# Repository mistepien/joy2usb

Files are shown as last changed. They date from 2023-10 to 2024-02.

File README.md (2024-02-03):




# joy2usb
Atari-like joystick adapter to USB.

<a href="https://github.com/mistepien/joy2usb/blob/main/joy2usb.pdf">Adapter</a> is actually a shield for 
<a href="https://learn.sparkfun.com/tutorials/pro-micro--fio-v3-hookup-guide/hardware-overview-pro-micro">Arduino Pro Micro based on ATmega 32U4</a>.

ATmega 32U4 has a hardware support for fullspeed USB, thus <a href="https://wiki.archlinux.org/title/mouse_polling_rate">polling rate 1000Hz</a> is not an issue for that chip.

You can use the <a href="https://github.com/mistepien/joy2usb/blob/main/production/joy2usb_6.2_2023-10-14_00-56-38/joy2usb_6.2.zip">gerber file<a> to order the PCB.

Attached   <a href="https://github.com/mistepien/joy2usb/blob/main/joy2usb.ino">code</a> uses port registers so that is quite efficient, debouncing is done without delay() function.

The adapter has a toggle C64/Amiga for choosing C64 or Amiga approach for FIRE2/FIRE3. According to <a href="http://wiki.icomp.de/wiki/DE-9_Joystick"> wiki.icomp.de website about DE-9 joystick</a>, FIRE2/FIRE3 are pulled to VCC in case of C64 and to GND in case of Amiga. That is not an issue for joy2usb due to XOR magic.

Two footprints are not trivial: DB9 male socket (<b>J1</b>) and SPDT switch (<b>SW2</b>).

Officialy the <b>J1</b> footprint (joy2usb has been designed in <a href="https://www.kicad.org/">KiCad</a>) is "DSUB-9_Male_Horizontal_P2.77x2.84mm_EdgePinOffset9.90mm_Housed_MountingHolesOffset11.32mm"
however it was chosen to fit <a href="https://www.tme.eu/pl/en/details/ld09p13a4gx00lf/d-sub-plugs-and-sockets/amphenol-communications-solutions/">   LD09P13A4GX00LF Amphenol</a>.

<b>SW2</b> supposed to be <a href="https://www.tme.eu/pl/en/details/mfp1220/slide-switches/knitter-switch/mfp-1220">Switch SPDT MFP 1220 KNITTER-SWITCH</a>, but it can be replaced with Pinheader 1x3/1x2 (pitch terminal 2.54mm) + jumper or any other SPDT switch with 3 pins and pitch terminal 2.54mm (e.g. <a href="https://www.tme.eu/pl/details/eg1218/przelaczniki-suwakowe/e-switch/">EG1218 E-SWITCH</a>).

<b>J2</b> is redundant -- you can use it to add some new features like autofire switch or sth. In attached firmware connecting PF4 to GND disables debouncing procedure. <b>If you connect PF5 to GND you can read FIRE1 CPS ("$cat /dev/ttyACM0" in Linux).</b>

Sometimes during uploading code to Arduino board you may face some issues -- then you will need to use RESET -- so <b>SW1</b> can be useful if you like to develope your own code.

BOM:
| Qty	| Reference(s) | Description |
|-----|---|---|
|3 | D1, D2, D3 | LEDs 3mm |  
|1 |	J1|	DB9 Male Connector <a href="https://www.tme.eu/pl/en/details/ld09p13a4gx00lf/d-sub-plugs-and-sockets/amphenol-communications-solutions/"> LD09P13A4GX00LF Amphenol</a> |
|1 |	J2|	2x4 Pinheader. pitch terminal: 2.54mm |
|3 | R1, R2, R3 | resistors for D1, D2 and D3 |
|2 | R4, R5	| resistors 10KΩ |
|1 | SW1 | Tact switch from Arduino breadboard projects |
|1 | SW2 | <a href="https://www.tme.eu/pl/en/details/mfp1220/slide-switches/knitter-switch/mfp-1220">Switch SPDT MFP 1220 KNITTER-SWITCH</a> |
|1 | U1 |	DIP20 socket (width 15.24mm) + <a href="https://learn.sparkfun.com/tutorials/pro-micro--fio-v3-hookup-guide/hardware-overview-pro-micro">Arduino Pro Micro</a> |

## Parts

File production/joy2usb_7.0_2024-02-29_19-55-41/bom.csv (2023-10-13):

Designator | Footprint | Quantity | Value | LCSC Part #
D1 | LED_D3.0mm_Oval | 1 | AMIGA
D2 | LED_D3.0mm_Oval | 1 | C64
D3 | LED_D3.0mm_Oval | 1 | STATUS
J1 | DSUB-9_Male_Horizontal_P2.77x2.84mm_EdgePinOffset9.90mm_Housed_OVAL_MountingHolesOffset11.32mm | 1 | DB9_Male
J2 | PinHeader_2x04_P2.54mm_Vertical | 1 | Conn_02x04_Odd_Even
R1, R2, R5 | R_Axial_DIN0207_L6.3mm_D2.5mm_P10.16mm_Horizontal_Oval | 3 | RxΩ
R3, R4 | R_Axial_DIN0207_L6.3mm_D2.5mm_P10.16mm_Horizontal_Oval | 2 | R10KΩ
SW1 | SW_PUSH_6mm_H4.3mm | 1 | RST
SW2 | E-Switch-EG1218-Manufacturer_Recommended_Oval | 1 | C64MODESW
U1 | DIP-24_W15.24mm_Socket_LongPads | 1 | Arduino_Pro_Micro

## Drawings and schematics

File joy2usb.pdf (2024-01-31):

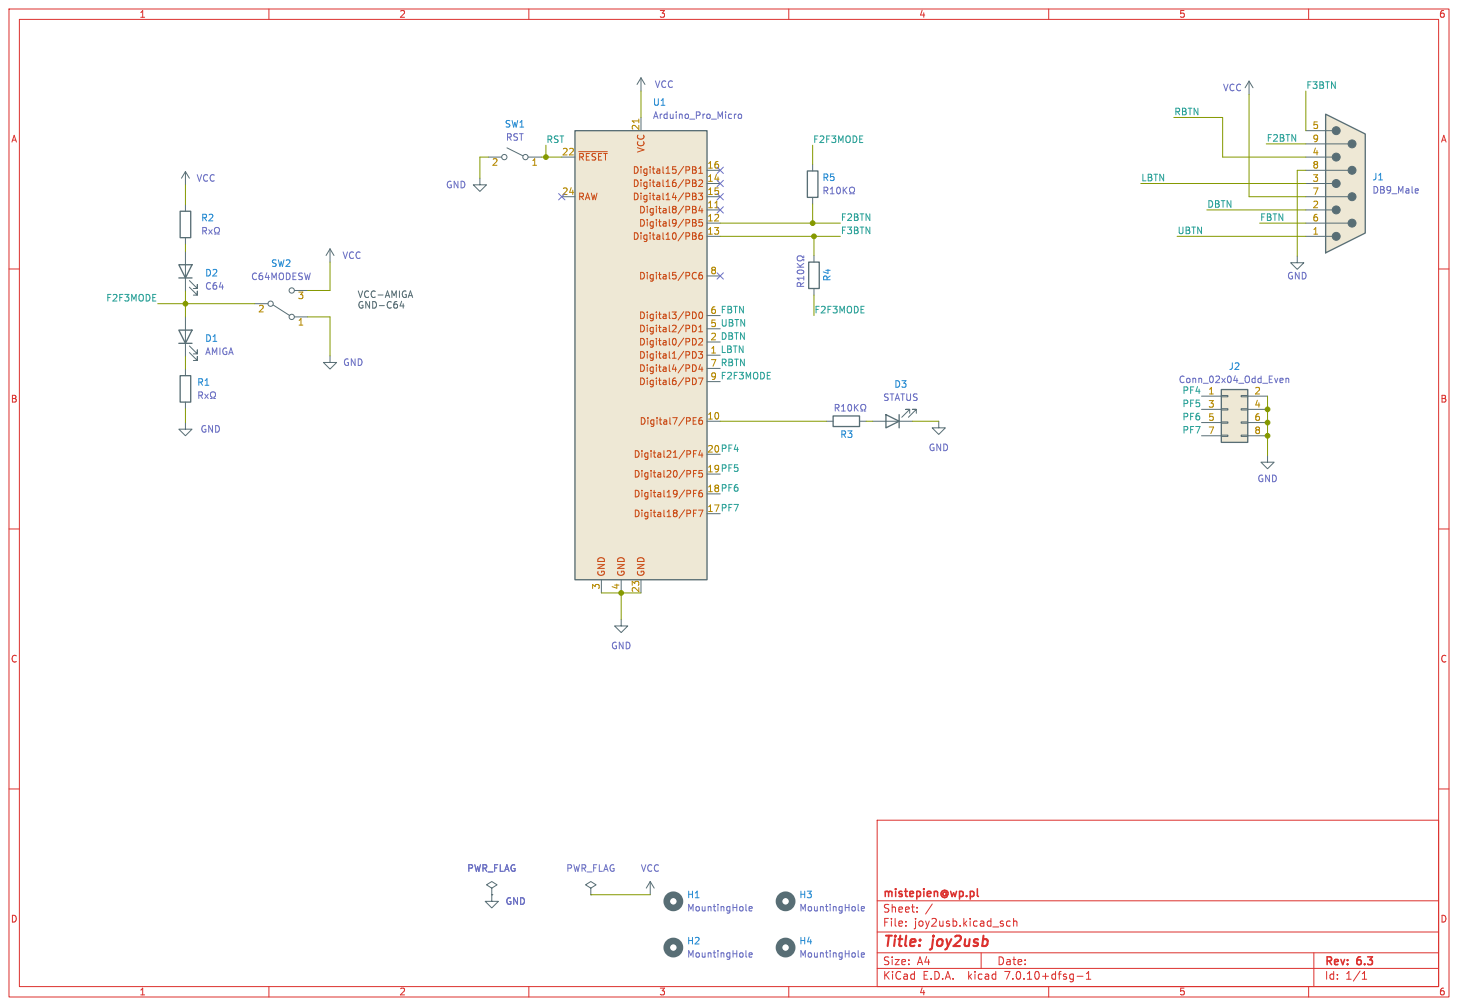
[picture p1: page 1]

File: joy2usb.kicad_sch Sheet: / mistepien@wp.pl R4 þÿR10K© D2 C64 R2

H4 MountingHole H3 MountingHole H1 MountingHole H2 MountingHole

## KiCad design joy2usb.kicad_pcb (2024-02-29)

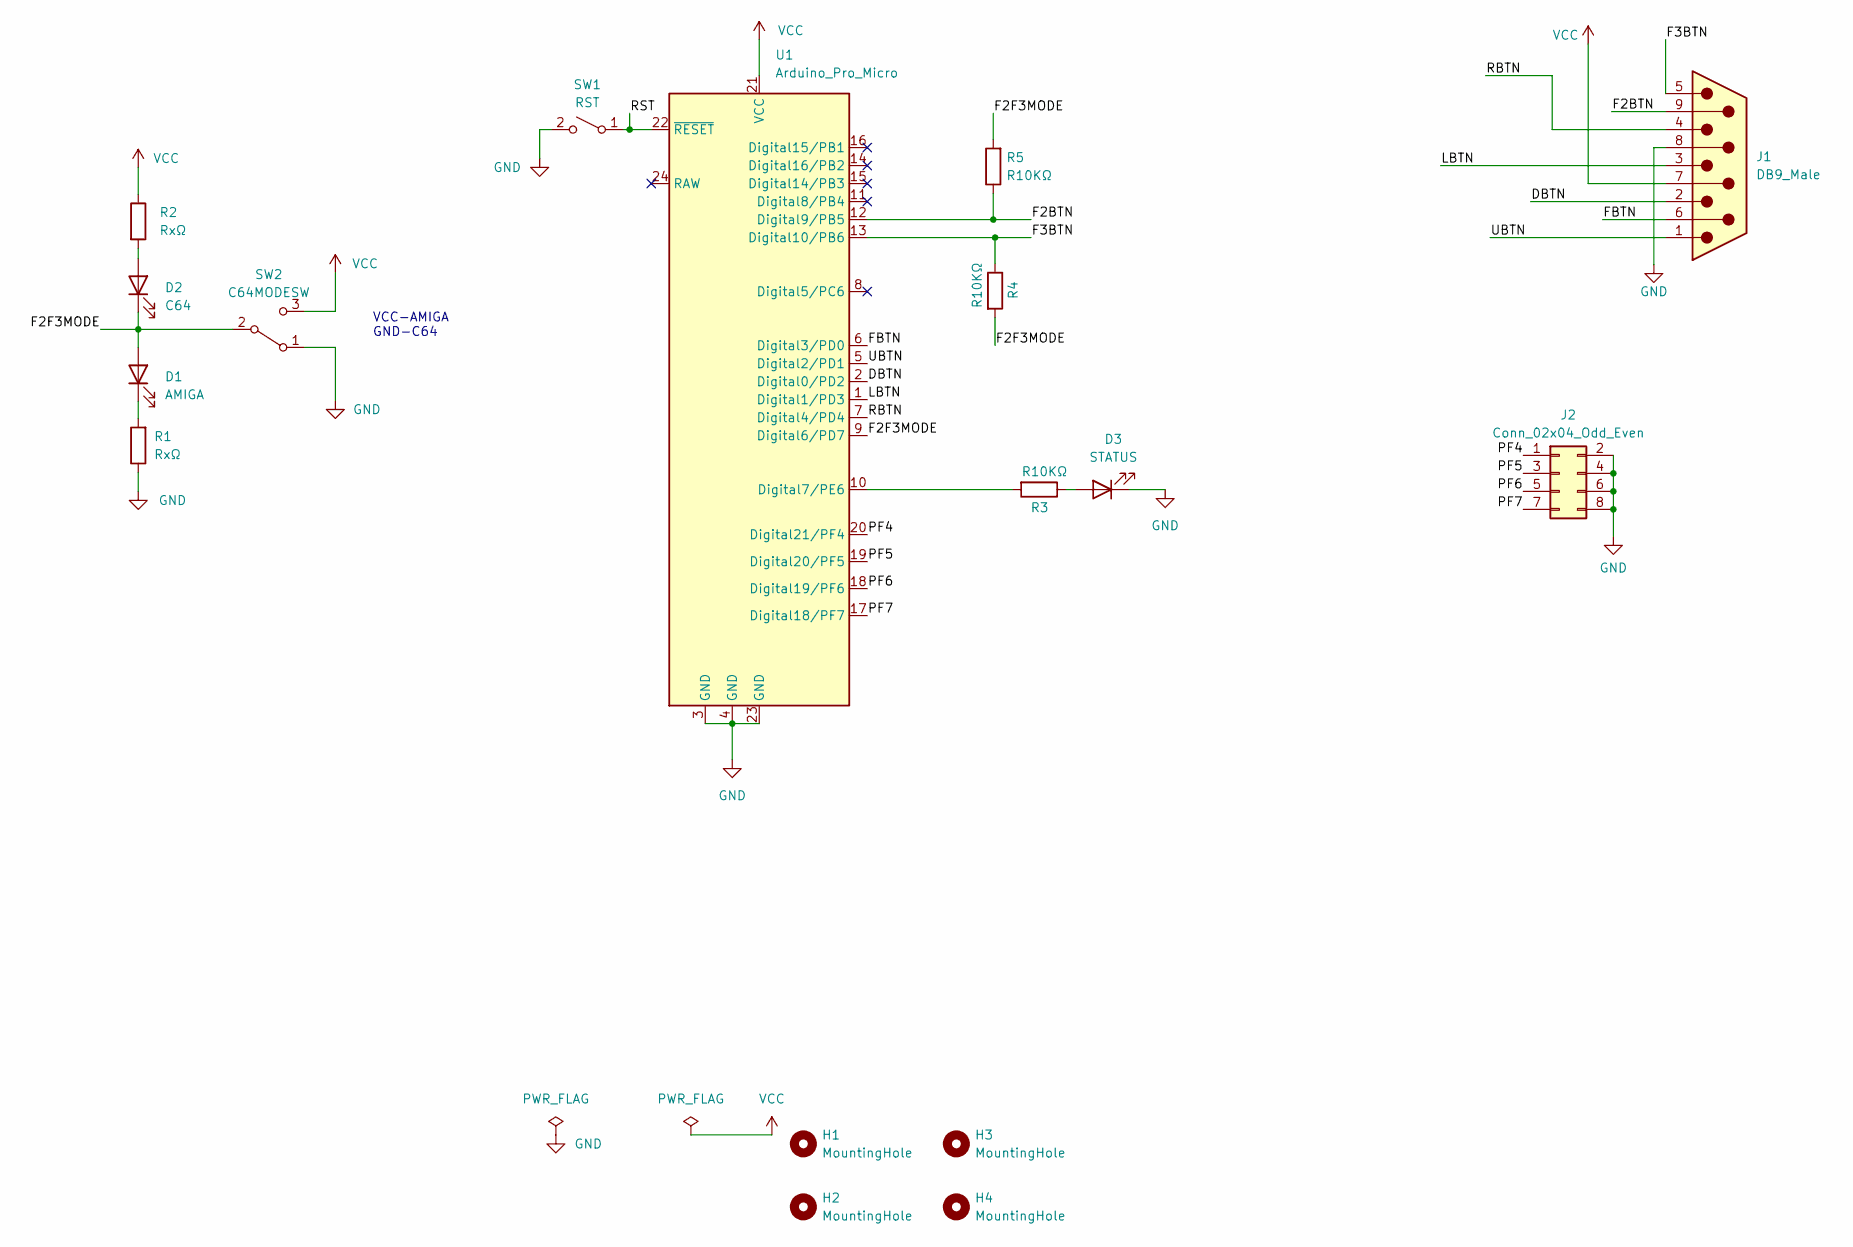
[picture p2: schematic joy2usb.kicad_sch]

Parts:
D1: AMIGA; LED_D3.0mm_Oval
D2: C64; LED_D3.0mm_Oval
D3: STATUS; LED_D3.0mm_Oval
H1, H2, H3, H4: MountingHole; MountingHole_3.5mm
J1: DB9_Male; DSUB-9_Male_Horizontal_P2.77x2.84mm_EdgePinOffset9.90mm_Hou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
J2: Conn_02x04_Odd_Even; PinHeader_2x04_P2.54mm_Vertical
R1, R2: RxΩ; R_Axial_DIN0207_L6.3mm_D2.5mm_P10.16mm_Horizontal_Oval
R3, R4, R5: R10KΩ; R_Axial_DIN0207_L6.3mm_D2.5mm_P10.16mm_Horizontal_Oval
SW1: RST; SW_PUSH_6mm_H4.3mm
SW2: C64MODESW; E-Switch-EG1218-Manufacturer_Recommended_Oval
U1: Arduino_Pro_Micro; DIP-24_W15.24mm_Socket_LongPads

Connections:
/DBTN: J1.2, U1.2 (Digital0/PD2)
/F2BTN: J1.9, R5.1, U1.12 (Digital9/PB5)
/F2F3MODE: D1.2 (A), D2.1 (K), R4.2, R5.2, SW2.2 (B), U1.9 (Digital6/PD7)
/F3BTN: J1.5, R4.1, U1.13 (Digital10/PB6)
/FBTN: J1.6, U1.6 (Digital3/PD0)
/LBTN: J1.3, U1.1 (Digital1/PD3)
/PF4: J2.1, U1.20 (Digital21/PF4)
/PF5: J2.3, U1.19 (Digital20/PF5)
/PF6: J2.5, U1.18 (Digital19/PF6)
/PF7: J2.7, U1.17 (Digital18/PF7)
/RBTN: J1.4, U1.7 (Digital4/PD4)
/RST: SW1.1 (A), U1.22 (~RESET)
/UBTN: J1.1, U1.5 (Digital2/PD1)
GND: D3.1 (K), J1.8, J2.2, J2.4, J2.6, J2.8, R1.1, SW1.2 (B), SW2.1 (A), U1.3 (GND), U1.4 (GND), U1.23 (GND)
unnamed: D1.1 (K), R1.2
unnamed: D2.2 (A), R2.2
unnamed: D3.2 (A), R3.1
unnamed: R3.2, U1.10 (Digital7/PE6)
VCC: J1.7, R2.1, SW2.3 (C), U1.21 (VCC)

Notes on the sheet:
VCC-AMIGA GND-C64

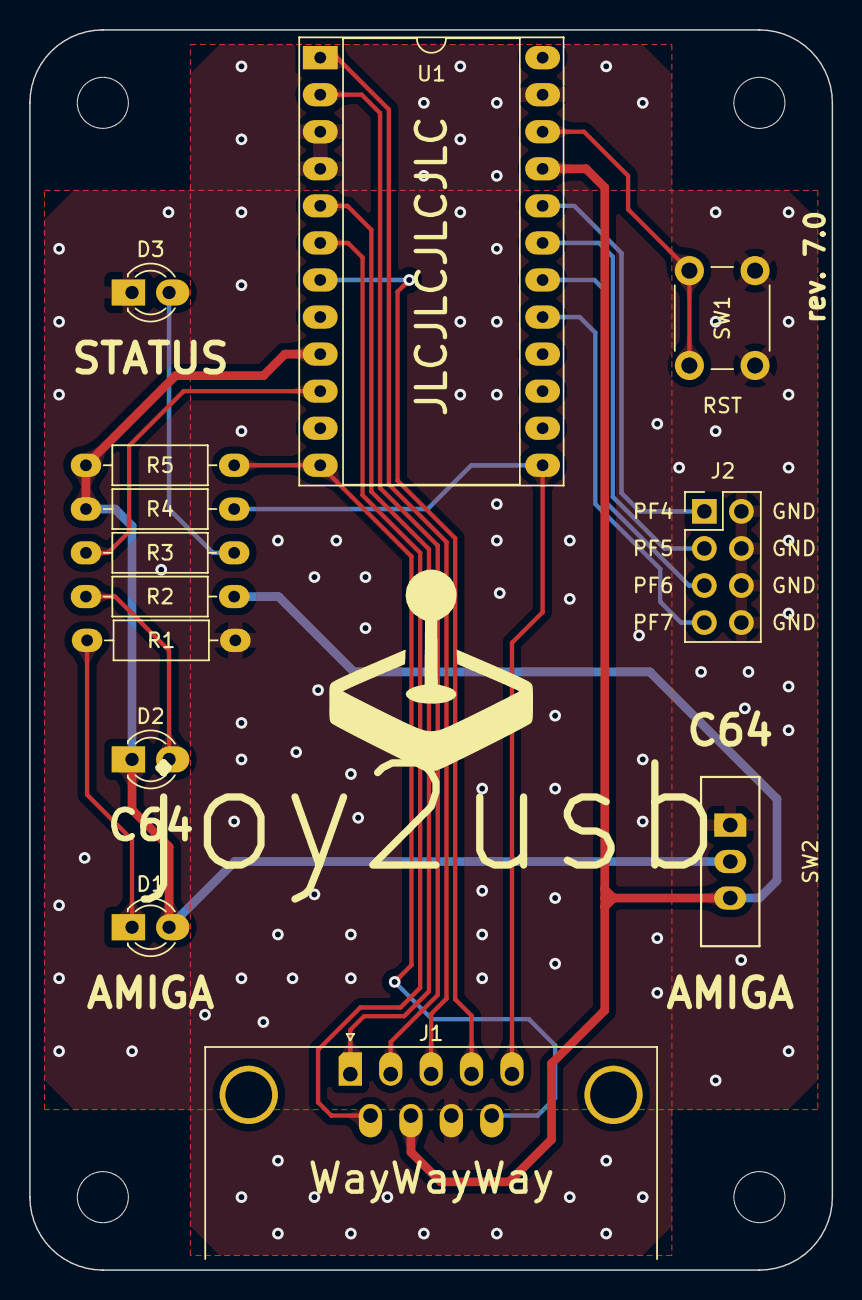
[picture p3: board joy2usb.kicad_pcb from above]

Board: 2 copper layers, 55.0 x 85.0 mm, 17 parts (0 on the bottom side), 19 nets.

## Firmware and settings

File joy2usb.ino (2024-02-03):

/*  joy2usb
    Author: mistepien@wp.pl

    Copyright (c) 2022, 2023 Michał Stępień

    GNU GENERAL PUBLIC LICENSE
    Version 3, 29 June 2007

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
*/


#define UP_BTN 1      //PIND
#define DOWN_BTN 2    //PIND
#define LEFT_BTN 3    //PIND
#define RIGHT_BTN 4   //PIND
#define C64MODE_PIN 7 //PIND
#define FIRE1 0       //PIND
#define FIRE2 5       //PINB
#define FIRE3 6       //PINB

#include <Joystick.h>  //https://github.com/MHeironimus/ArduinoJoystickLibrary
#include <math.h>

byte minimal_axis_time;
byte minimal_button_time;

byte pinf = 0;

Joystick_ Joystick(JOYSTICK_DEFAULT_REPORT_ID, JOYSTICK_TYPE_JOYSTICK,
                   3, 0,                  // Button Count, Hat Switch Count
                   true, true, false,     // X and Y, but no Z Axis
                   false, false, false,   // No Rx, Ry, or Rz
                   false, false,          // No rudder or throttle
                   false, false, false);  // No accelerator, brake, or steering


void debouncing(bool mode = 1) {
  if (mode) {
    minimal_axis_time = 8;
    minimal_button_time = 10;
  } else {
    minimal_axis_time = 0;
    minimal_button_time = 0;
  }
}

void setup() {
  Serial.begin(9600);
  bitSet(DDRE, 6); bitClear(PORTE, 6); //STATUSLED(PE6) as OUTPUT + set to LOW


  bitClear(DDRF, 4); bitSet(PORTF, 4); //INPUT_PULLUP FOR DEBOUNCING SWITCH
  bitClear(DDRF, 5); bitSet(PORTF, 5); //INPUT_PULLUP FOR FIRE1 CPS MEASURE
  bitClear(DDRF, 6); bitSet(PORTF, 6);
  bitClear(DDRF, 7); bitSet(PORTF, 7);

  DDRD &= ~( bit(UP_BTN) | bit(DOWN_BTN) | bit(LEFT_BTN) | bit(RIGHT_BTN) | bit(FIRE1) | bit(C64MODE_PIN)) ;  //PD0-PD5 as INPUT
  PORTD |= ( bit(UP_BTN) | bit(DOWN_BTN) | bit(LEFT_BTN) | bit(RIGHT_BTN) | bit(FIRE1)); //FIRE1,UP,DOWN,LEFT,RIGT as INPUT_PULLUP

  DDRB &= ~( bit(FIRE2) | bit(FIRE3)); //FIRE2 and FIRE3 as INPUT

  //UNUSED PINS
  DDRB &= ~( bit(PB1) | bit(PB2) | bit(PB3) | bit(PB4));  //PB1-PB4 as INPUT_PULLUP -- unused_pins
  PORTB  |= bit(PB1) | bit(PB2) | bit(PB3) | bit(PB4);
  bitClear(DDRC, 6); bitSet(PORTC, 6); //INPUT_PULLUP PC6 -- unused pin

  Joystick.setXAxisRange(-1, 1);
  Joystick.setYAxisRange(-1, 1);
  Joystick.begin(false);
  Joystick.setXAxis(0);
  Joystick.setYAxis(0);

  delay(1500); /*very ugly and dirty hack
                without that delay() joystick will not
                be centered at the beginning (that is an
                issue with Joystick.sendState();
*/

  Joystick.sendState();

  /*turn off RX and TX LEDS
    on permanent basis

    turning off these LEDS here at the end of setup()
    is an indicator that joy2usb is ready
  */
  bitClear(DDRD, 5);
  bitClear(DDRB, 0);

  bitSet(PORTE, 6); //STATUSLED(PE6) set to HIGH
}

byte joystate_update() {
  //UP,DOWN,LEFT,RIGHT,F1,F2,F3
  //0, 1,   2,   3,   ,4, 5, 6
  byte pind = ~PIND;
  byte pinb = ~PINB;

  bool C64MODE = bitRead(pind, C64MODE_PIN);
  pind &= (bit(UP_BTN) | bit(DOWN_BTN) | bit(LEFT_BTN) | bit(RIGHT_BTN) | bit(FIRE1));
  pinb &= (bit(FIRE2) | bit(FIRE3));
  bitWrite(pinb, FIRE2, (C64MODE ^ bitRead(pinb, FIRE2)));
  bitWrite(pinb, FIRE3, (C64MODE ^ bitRead(pinb, FIRE3)));
  byte joystate_current = ((pind >> 1) | ((pind & bit(FIRE1)) << 4) | (pinb));
  return joystate_current;
}

//NO-OPPOSITE-DIRECTIONS
bool nod(bool OUT_DIR, bool SECOND_DIR) {
  //bool value = ((!( OUT_DIR  || SECOND_DIR )) || OUT_DIR); //logic where LOW=pressed, HIGH=released
  bool value = ((!( OUT_DIR  && SECOND_DIR )) && OUT_DIR); //logic where HIGH=pressed, LOW=released
  return value;
}

unsigned long prev_button_time[3] = { 0, 0, 0 };
unsigned long prev_axis_time[4] = { 0, 0, 0, 0 };
byte prev_axises;
byte prev_buttons;

void joystate_to_usb(byte joystate) {

  byte current_axises = joystate & B00001111;
  byte current_buttons = (joystate >> 4);

  byte changedAxises = current_axises ^ prev_axises;
  byte changedButtons = current_buttons ^ prev_buttons;

  if (changedAxises || changedButtons) {
    debouncing(bitRead(pinf, 4));
    unsigned long current_time = millis();  //ONE common millis() for AXISES AND BUTTONS SECTIONS

    //####################################################
    if (changedAxises) {  //AXISES SECTION
      byte JOY_D = 0;
      byte JOY_U = 0;
      byte JOY_R = 0;
      byte JOY_L = 0;
      byte axisXchanged = 0;
      byte axisYchanged = 0;
      for (byte index = 0; index < 4; index++) {
        if (bitRead(changedAxises, index)) {
          if (current_time - prev_axis_time[index] > minimal_axis_time) {
            prev_axis_time[index] = current_time;
            prev_axises = current_axises;

            bool btn_state = bitRead(current_axises, index);
            switch (index) {
              case 0:  //UP
                JOY_U = btn_state;
                axisYchanged = 1;
                break;
              case 1:  //DOWN
                JOY_D = btn_state;
                axisYchanged = 1;
                break;
              case 2:  //LEFT
                JOY_L = btn_state;
                axisXchanged = 1;
                break;
              case 3:  //RIGHT
                JOY_R = btn_state;
                axisXchanged = 1;
                break;
            }
          }
        }
      }
      if (axisYchanged) {
        Joystick.setYAxis(nod(JOY_D, JOY_U) - nod(JOY_U, JOY_D));
      }
      if (axisXchanged) {
        Joystick.setXAxis(nod(JOY_R, JOY_L) - nod(JOY_L, JOY_R));
      }
    }

    //##############################################
    if (changedButtons) {  //BUTTONS SECTION
      for (byte index = 0; index < 3; index++) {
        if (bitRead(changedButtons, index)) {
          if (current_time - prev_button_time[index] > minimal_button_time) {
            prev_button_time[index] = current_time;
            prev_buttons = current_buttons;
            Joystick.setButton(index, bitRead(current_buttons, index));
          }
        }
      }
    }
  }
  Joystick.sendState();  //ONE common send.State for AXISES AND BUTTONS SECTIONS
}

byte prev_fire1_state = 0;
int counter = 0;
unsigned long prev_time = 0;
const byte probe_time_SEC = 2;
void measure_freq() {
  byte pind = ~PIND;
  bool current_fire1_state = bitRead(pind, FIRE1);
  bool changed_fire1_state = current_fire1_state ^ prev_fire1_state;
  if ( changed_fire1_state ) {
    prev_fire1_state = current_fire1_state;
    if ( current_fire1_state ) {
      counter++;
    };
  }

  unsigned long current_time = millis();
  if (  current_time - prev_time >  probe_time_SEC * 1000 ) {
    Serial.print(current_time);
    Serial.print(": CPS: ");
    float cps = (float) counter / ( float ) probe_time_SEC;
    Serial.println(cps, 1);
    prev_time = millis();
    counter = 0;
  }
}

void loop() {
  while (1) {
    pinf = PINF;
    if ( bitRead(pinf, 5) ) {
      joystate_to_usb(joystate_update());
    } else {
      measure_freq();
    }
  }
}

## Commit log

2022-11-04 Initial commit rev. 1.0
    [joy2usb.kicad_pcb, joy2usb.kicad_sch]
2022-11-05 Fixing of annoying bug
    [joy2usb.ino]
2022-11-07 PCB Rev. 2.0
    Diode D1 is turned on in the same way as PULL-DOWN for the C64 Mode. Thus when D1 is on it means that PULL-DOWN for the C64 Mode is on, too.
    [joy2usb.kicad_pcb, joy2usb.kicad_sch]
2022-11-07 PCB Rev. 2.0
2022-11-11 PCB Rev. 2.1
    Slightly wider signal tracks and better symmetry.
    [joy2usb.kicad_pcb]
2022-11-19 PCB Rev. 2.2
    Bigger mass field
    [joy2usb.kicad_pcb]
2022-11-20 PCB Rev. 2.3
    Update of footprints -- oval pads
    [joy2usb.kicad_pcb, joy2usb.kicad_sch]
2022-11-20 PCB Rev. 2.3
2022-11-20 PCB Rev. 2.3
    Updated pads
    [joy2usb.kicad_pcb]
2022-11-28 Schematic Rev. 2.1
    few cosmetic updates
2022-11-29 PCB Rev. 2.4
    update: rounded corners
    [joy2usb.kicad_pcb]
2022-11-29 PCB Rev. 2.41
    fix: update of nets
    [joy2usb.kicad_pcb]
2022-12-07 fixing problem with C64 mode startup
    Arduino micro clone has some issues with reading pins in setup().
    [joy2usb.ino]
2022-12-11 PCB Rev. 2.5
2022-12-11 PCB Rev. 2.5
    Update of LED footprint
    [joy2usb.kicad_pcb, joy2usb.kicad_sch]
2022-12-18 PCB Rev. 3.0
    Replace GND1 and GND2 with GND.
    [joy2usb.kicad_pcb, joy2usb.kicad_sch]
2022-12-18 PCB Rev. 3.1
    Several cosmetic PCB updates
    [joy2usb.kicad_pcb]
2023-01-10 Shorter delay time in setup()
    [joy2usb.ino]
2023-01-21 PCB Rev. 4.0
    update C64/Amiga switch
    [joy2usb.kicad_pcb, joy2usb.kicad_sch]
2023-05-19 PCB Rev. 4.1
    SW2 minor amendment
    [joy2usb.kicad_pcb, joy2usb.kicad_sch]
2023-05-19 Update README.md
    adding information about EG1218 E-SWITCH
2023-06-07 PCB Rev. 5.0
    Minor update of DB9 socket footprint.
2023-06-25 New feature: option to disable debouncing
    New feature: option to disable debouncing
    To disable debouncing short PF4 and GND (eg. with jumper). Useful for "gamepad to db9" joystick adapters.
    [joy2usb.ino]
2023-07-04 Reliable checking of C64 MODE switch in setu()
2023-10-13 PCB Rev. 6.2
    removal of ic 4066
    [joy2usb.kicad_pcb, joy2usb.kicad_sch]
2023-10-13 PCB Rev. 6.2
    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
    [bom.csv, designators.csv, positions.csv]
2023-10-28 PCB Rev. 6.3
    WayWayWay text on silkscreen for PCBWay is added
2024-01-31 rev. 6.3
    update of description of one resistor
2024-02-29 added teardrops
    [bom.csv, designators.csv, positions.csv]

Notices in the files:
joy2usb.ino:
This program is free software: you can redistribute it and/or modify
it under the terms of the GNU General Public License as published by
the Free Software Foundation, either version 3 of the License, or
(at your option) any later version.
